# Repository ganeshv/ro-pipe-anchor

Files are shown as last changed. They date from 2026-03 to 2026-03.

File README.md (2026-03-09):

# RO Pipe Anchor

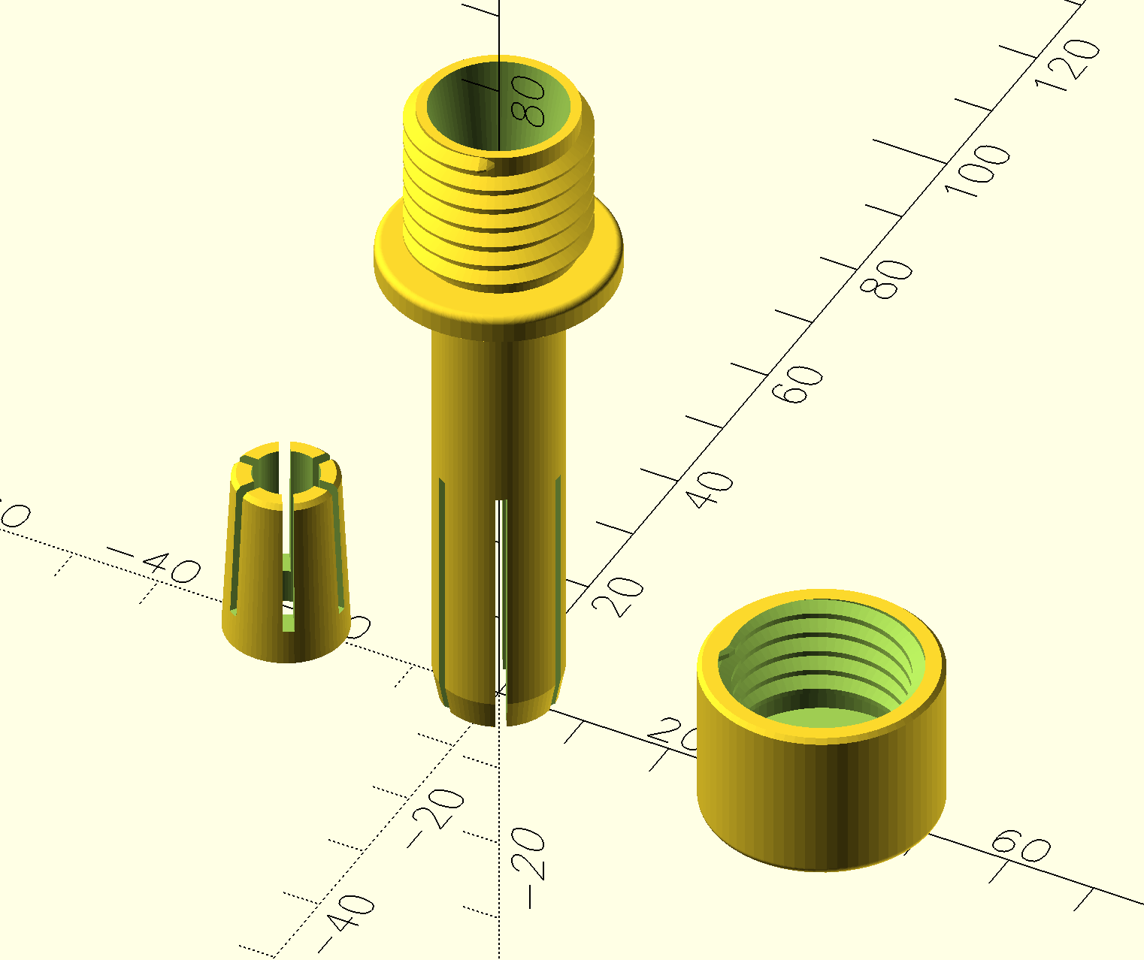
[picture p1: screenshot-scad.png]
OpenSCAD screenshot of the 3D model


A 3D-printable, three-part pass-through conduit designed to securely route a 1/4" (6.5mm OD) Reverse Osmosis (RO) exhaust/drain tube through a kitchen counter and into a drain pipe below.

## The Problem
Standard RO exhaust lines are often just pushed through a hole in the counter and routed into a PVC drain pipe. Without proper securement, any movement or bumping under the counter can pull the tube out of the drain, leading to water spills. 

## The Solution
This design provides a solid anchor point at the counter level:
1. **Counter Conduit (Part 1):** Sits flush in a 15mm counter hole, extending down to help guide the tube toward the drain. The lower portion features a compressible collet section that self-centers and grips the inside of the counter hole.
2. **Collet (Part 2):** A tapered collet mechanism (similar to a drill chuck or rotary tool) fits into the conduit. The conduit has a tapered bore inside, so the more you push the collet in, its fingers come together and grip the 6.5mm RO pipe passing through it firmly, preventing it from slipping up or down. 
2. **Cap (Part 3):** Screws onto the top of the conduit, sandwiching the collet. As you tighten the cap, the collet is pushed in, tightening the grip on the pipe.

## Features
* **Adjustable Grip:** The threaded collet design allows you to control exactly how tight the grip is on the pipe without relying on perfect 3D printer tolerances.
* **Parametric Design:** Built in OpenSCAD using the BOSL2 library. Easy to adjust for different counter thicknesses, hole sizes, or tube diameters.

## Printing Instructions
* I use default settings on the Prusa Mini: Generic PLA, 0.15mm QUALITY.
* I prefer to print the conduit with custom supports for the flange, threaded section on top. Don't like supports on threads, which would happen the other way round.

## Assembly Instructions
* Thread the pipe first through the cap, then collet, then conduit.
* Push the conduit into the counter until the flange touches the counter. It should be a firm fit, not too easy to pull out.
  * If it comes off too easily, try a layer of tape on the solid part of the shaft. Or reprint with slightly increased diameter.
  * Future enhancement: Add teeth to the fingers of the conduit so they come out of the hole and expand to grip the bottom surface.
* Route the pipe below the counter wherever you need it to go.
* Push the collet in, screw the cap.
* The cap must be turned just enough so the pipe cannot be dislodged with a simple pull. Avoid overtightening.

## Similar Use Cases
While originally designed for RO water filters, this is effectively a **Panel-Mount Collet Fitting**, **Pass-Through Compression Gland**, or **Bulkhead Tube Strain Relief**. It can be adapted for any scenario requiring a hard plastic tube to be securely routed through a panel or surface:
* **Hydroponics & Aeroponics:** Routing 1/4" irrigation lines or drip-feed tubes through the lids of plastic reservoirs or grow-tent walls to prevent the tube from slipping.
* **Aquarium Systems:** Running rigid airline tubing, CO2 lines, or auto-top-off (ATO) water lines through cabinet tops or aquarium hoods.
* **Pneumatic / Air Lines:** Passing rigid polyurethane air lines through workbench tops or shop walls for compressors and tools.
* **Home Brewing:** Routing gas or liquid lines through the top of a kegerator or a bar counter.

## Dependencies
To modify or render the `.scad` file, you will need:
* [OpenSCAD](https://openscad.org/)
* [BOSL2 Library](https://github.com/BelfrySCAD/BOSL2)

## Credits
Designed in collaboration with Claude Opus 4.6

## License
[MIT License](LICENSE)

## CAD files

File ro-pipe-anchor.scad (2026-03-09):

/* ========================================================
   RO Pipe Counter Conduit with Collet Grip  —  v2
   
   Two-part fitting to route a 6.5mm blue RO exhaust pipe
   through a kitchen counter and hold it securely.
   
   Part 1 — Counter conduit:
     Shaft sits in 15mm counter hole, flange lip on surface,
     threaded post above with internal compression taper.
   
   Part 2 — Collet cap:
     Screws onto post. Collet fingers hang from a solid top
     plate down into the tapered bore. Tightening drives
     fingers deeper into the taper, compressing onto pipe.
   
   Assembly:
     1. Thread blue pipe through Part 2 from the top
     2. Drop Part 1 shaft into counter hole (flange sits flush)
     3. Push blue pipe down through Part 1 until tip reaches
        PVC drain (~11mm below counter bottom)
     4. Screw Part 2 onto Part 1 — collet grips the pipe
   
   Printing (PLA):
     - Part 1: upright, flange at top. No supports needed.
     - Part 2: flip so flat cap top is on bed, fingers up.
     - 0.2mm layers, 3+ perimeters, 30%+ infill
     - Thread tolerance tunable via thread_tol
   ======================================================== */

include <BOSL2/std.scad>
include <BOSL2/threading.scad>

// ===================== PARAMETERS =====================

// Blue RO exhaust pipe
pipe_od         = 6.5;      // measured outer diameter

// Counter
counter_thick   = 57;       // counter thickness

// Shaft (sits inside counter hole)
shaft_od        = 14;       // fits in 15mm hole
shaft_bore      = 8;        // blue pipe passes through easily

// Shaft collet (lower portion of shaft has fingers)
shaft_collet_frac = 0.6;    // fraction of shaft that's fingered (0.6 = 60%)
shaft_collet_n   = 6;       // number of fingers
shaft_slit_w     = 1.2;     // slit width
shaft_lead_in    = 4;       // tapered lead-in at bottom tip (mm)
shaft_lead_od    = 12.5;    // OD at very bottom of lead-in (narrows to enter)

// Flange / lip (rests on counter surface)
flange_od       = 26;       // wider than 15mm hole
flange_h        = 3;

// Thread (joins the two parts)
thread_d        = 20;       // nominal diameter
thread_pitch    = 2.5;      // coarse for PLA reliability
thread_tol      = 0.4;      // increase if thread too tight

// Threaded post (rises above flange)
post_h          = 18;

// Compression taper inside the post
taper_top_id    = 15;       // wide mouth at top of post
taper_bot_id    = 10;       // narrow at bottom — squeezes fingers
taper_h         = 14;       // most of the post depth is taper

// Collet fingers (part of cap, compress around pipe)
collet_n        = 6;        // number of fingers
collet_slit_w   = 1.2;      // slit width between fingers
collet_len      = 20;       // finger length (hangs into post)
collet_od       = 13.5;     // finger ring OD — must enter taper_top_id
collet_tip_od   = 11.5;     // finger tip OD — slightly > taper_bot_id for grip
collet_id       = pipe_od + 0.8;  // relaxed bore — pipe slides through

// Cap body
cap_od          = 26;
cap_wall        = 3;        // wall thickness of threaded ring
cap_thread_len  = 14;       // threaded engagement length
cap_top_h       = 4;        // solid top plate thickness
pipe_exit_d     = shaft_bore; // hole in cap top for pipe

// Cosmetic
$fn             = 72;

// ===================== RENDER MODE =====================
// "part1"     — counter conduit only
// "part2"     — cap only (print orientation)
// "part3"     — collet only (print orientation)
// "all"       — both parts side by side for printing
// "assembled" — cross-section showing how they mate

render_mode = "all";


// ===================== PART 1: COUNTER CONDUIT =====================

module part1_conduit() {
    shaft_collet_len = counter_thick * shaft_collet_frac;
    shaft_solid_len  = counter_thick - shaft_collet_len;

    difference() {
        union() {
            // Upper solid shaft section (connects to flange)
            up(shaft_collet_len)
                cyl(d=shaft_od, h=shaft_solid_len, anchor=BOTTOM);

            // Flange — sits on counter surface
            up(counter_thick)
                cyl(d=flange_od, h=flange_h, anchor=BOTTOM,
                    rounding2=0.8);

            // Threaded post above flange
            up(counter_thick + flange_h)
                threaded_rod(
                    d      = thread_d,
                    l      = post_h,
                    pitch  = thread_pitch,
                    anchor = BOTTOM
                );
        }

        // Bore through solid shaft + flange
        down(1)
            cyl(d=shaft_bore, h=counter_thick + flange_h + 2,
                anchor=BOTTOM);

        // Tapered bore inside the post (compression cone)
        up(counter_thick + flange_h + (post_h - taper_h))
            cyl(d1=taper_bot_id, d2=taper_top_id, h=taper_h,
                anchor=BOTTOM);

        // Straight bore below the taper
        up(counter_thick + flange_h - 1)
            cyl(d=taper_bot_id, h=post_h - taper_h + 2,
                anchor=BOTTOM);
    }

    // Shaft collet fingers — added outside difference() so
    // nothing cuts into them
    shaft_collet_fingers(shaft_collet_len);
}

module shaft_collet_fingers(collet_len) {
    difference() {
        union() {
            // Main finger cylinder at shaft OD
            up(shaft_lead_in)
                cyl(d=shaft_od, h=collet_len - shaft_lead_in,
                    anchor=BOTTOM);

            // Tapered lead-in at bottom
            cyl(d1=shaft_lead_od, d2=shaft_od,
                h=shaft_lead_in, anchor=BOTTOM,
                chamfer1=0.5);
        }

        // Bore for blue pipe
        down(1)
            cyl(d=shaft_bore, h=collet_len + 2, anchor=BOTTOM);

        // Slits to create fingers
        for (i = [0 : shaft_collet_n - 1]) {
            rot(i * 360 / shaft_collet_n)
                translate([0, -shaft_slit_w / 2, -1])
                    cube([shaft_od / 2 + 1, shaft_slit_w,
                          collet_len - 2]);  // stop 3mm from top (solid ring)
        }
    }
}


// ===================== PART 2: COLLET CAP =====================

module part2_cap() {
    $slop = thread_tol;

    cap_total_h = cap_top_h + cap_thread_len;

    // Cap body with female thread
    difference() {
        union() {
            // Solid outer cylinder for threaded section
            cyl(d=cap_od, h=cap_thread_len, anchor=BOTTOM,
                chamfer1=0.5);

            // Solid top plate
            up(cap_thread_len)
                cyl(d=cap_od, h=cap_top_h, anchor=BOTTOM,
                    rounding2=1);
        }

        // Cut female thread into the outer cylinder
        down(0.5)
            threaded_rod(
                d        = thread_d,
                l        = cap_thread_len + 1,
                pitch    = thread_pitch,
                internal = true,
                anchor   = BOTTOM
            );

        // Pipe hole through top plate
        up(cap_thread_len - 1)
            cyl(d=pipe_exit_d, h=cap_top_h + 2, anchor=BOTTOM);
    }

    /*
     * better make the collet a separate part instead of joined to the cap

    // Collet fingers — added AFTER difference so the thread
    // cut doesn't destroy them
    collet_start_z = cap_thread_len;
    up(collet_start_z - collet_len)
        collet_fingers();
    */
}


module collet_fingers() {
    difference() {
        // Tapered cylinder — wider at top (attachment), narrower at tips
        cyl(d1=collet_tip_od, d2=collet_od,
            h=collet_len, anchor=BOTTOM,
            chamfer1=0.5);

        // Bore for pipe
        down(1)
            cyl(d=collet_id, h=collet_len + 2, anchor=BOTTOM);

        // Slits creating individual fingers
        for (i = [0 : collet_n - 1]) {
            rot(i * 360 / collet_n)
                translate([0, -collet_slit_w / 2, -1])
                    cube([collet_od, collet_slit_w,
                          collet_len - 3]);  // slits stop 2mm from top (keeps ring)
        }
    }
}


// ===================== LAYOUT / RENDER =====================

if (render_mode == "part1") {
    part1_conduit();

} else if (render_mode == "part2") {
    // Print orientation: cap top face on bed, fingers up
    cap_total = cap_top_h + cap_thread_len;
    up(cap_total) xrot(180)
        part2_cap();

} else if (render_mode == "part3") {
    up(collet_len) xrot(180)
        collet_fingers();

} else if (render_mode == "all") {
    // Side by side for print plate
    part1_conduit();

    cap_total = cap_top_h + cap_thread_len;
    right(flange_od / 2 + cap_od / 2 + 12)
        up(cap_total) xrot(180)
            part2_cap();

    left(flange_od / 2 + 12)
        up(collet_len) xrot(180)
            collet_fingers();
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
